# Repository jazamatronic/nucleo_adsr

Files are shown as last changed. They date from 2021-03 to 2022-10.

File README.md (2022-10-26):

# nucleo_adsr
STM32L432 based triple ADSR envelope generator



Very small sound demo with it in action [here](https://imgur.com/a/Ze2JWVJ)

ST generated files have their own license headers.

*NOTE* - R1, R5 and R9 should be 100k, not 2k as shown in the schematics.

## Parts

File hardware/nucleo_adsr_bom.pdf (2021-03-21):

Feuille1

# nucleo_adsr

Sun Mar 21 23:03:33 2021
Eeschema 5.1.5+dfsg1-2build2 Component Count:64
Ref | Value | Description
C1, C2, C3, C4, C5, C6, C13, C15 | 0.1u | Polarized capacitor, small symbol
C7, C8, C9 | 100p | Unpolarized capacitor, small symbol
C10, C11, C12 | 10n | Unpolarized capacitor, small symbol
C14, C16 | 10u | Polarized capacitor, small symbol
D1 | LED_RABG | RGB LED, red/anode/blue/green
J1 | ENV1 | Audio Jack, 2 Poles (Mono / TS), Switched T Pole (Normalling)
J2 | TRIG1 | Audio Jack, 2 Poles (Mono / TS), Switched T Pole (Normalling)
J3 | ENV2 | Audio Jack, 2 Poles (Mono / TS), Switched T Pole (Normalling)
J4 | TRIG2 | Audio Jack, 2 Poles (Mono / TS), Switched T Pole (Normalling)
J5 | ENV3 | Audio Jack, 2 Poles (Mono / TS), Switched T Pole (Normalling)
J6 | TRIG3 | Audio Jack, 2 Poles (Mono / TS), Switched T Pole (Normalling)
J7 | PWR_HDR | Generic connector, double row, 02x08, odd/even pin numbering scheme
Q1, Q2, Q3, Q4, Q5, Q6 | BC547 | 0.1A Ic, 45V Vce, Small Signal NPN Transistor, TO-92
R1, R5, R9 | 2k | Resistor, small symbol
R2, R6, R10 | 1k | Resistor, small symbol
R3, R7, R11 | 10k | Resistor, small symbol
R4, R8, R12 | 4k7 | Resistor, small symbol
R13, R14, R15 | 100k | Resistor, small symbol
R16, R17, R18 | 3k6 | Resistor, small symbol
R19, R20, R21 | 68k | Resistor, small symbol
RV1, RV2, RV3 | 100k | Potentiometer
RVA1, RVD1, RVR1, RVS1 | 100k
SW1 | SW_Push | Push button switch, generic, two pins
U1 | NUCLEO-L432KC
U2, U3, U4 | LF398_SOIC14 | Sample And Hold Unity Gain Follower, SOIC-14
U5 | TL074 | Quad Low-Noise JFET-Input Operational Amplifiers, DIP-14/SOIC-14

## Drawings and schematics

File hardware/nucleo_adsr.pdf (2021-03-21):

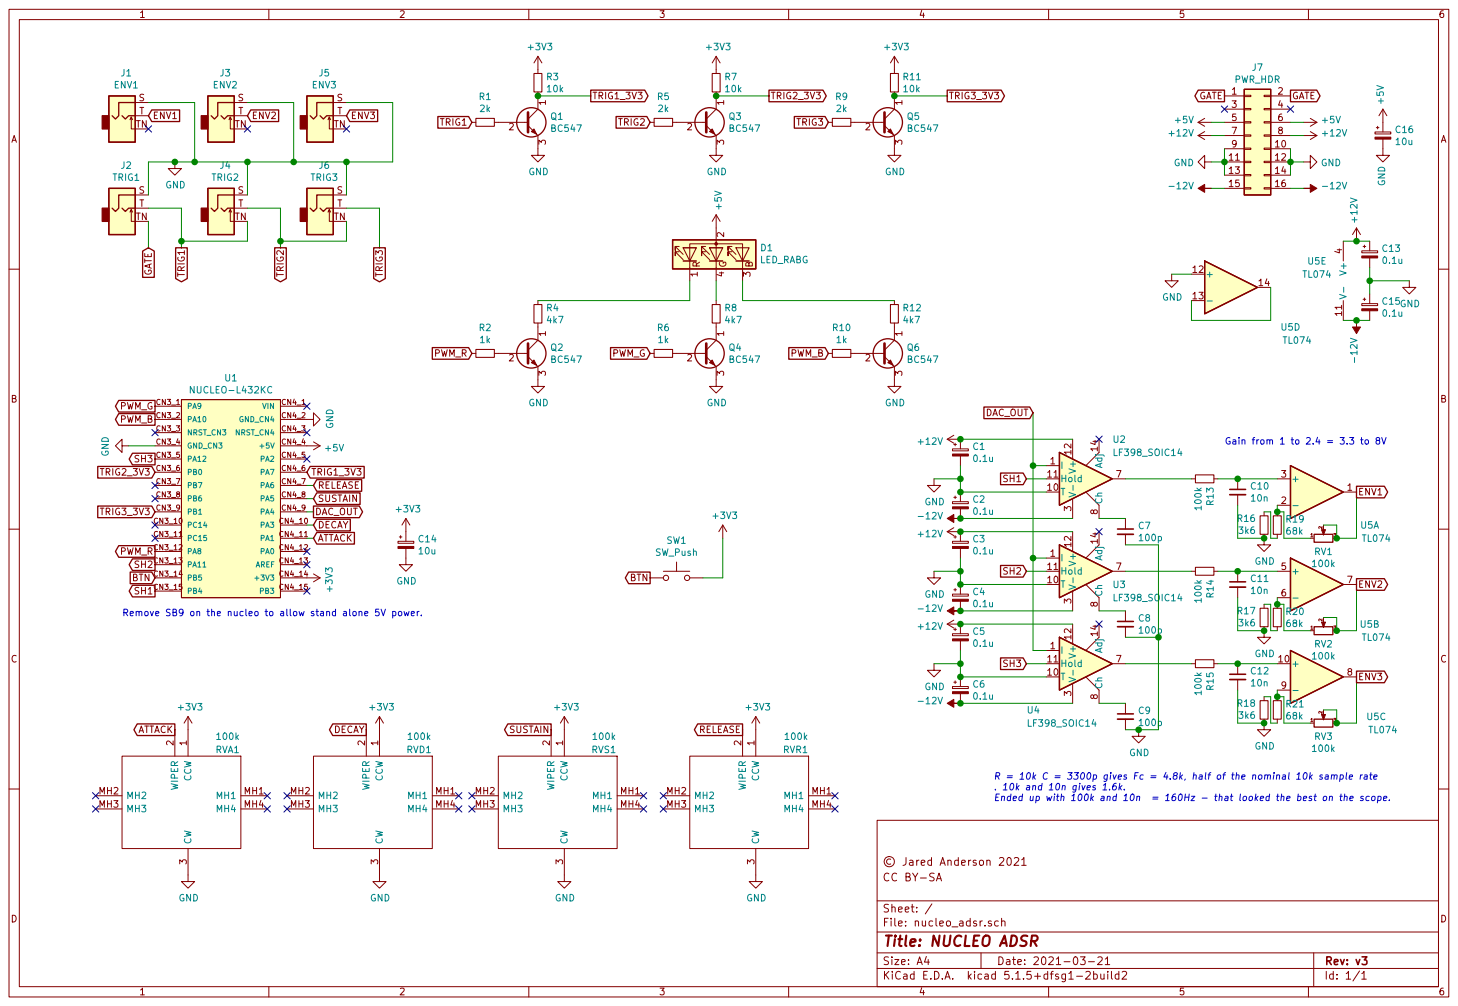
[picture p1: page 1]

11 | 12
13 | 14

Ended up with 100k and 10n = 160Hz - that looked the best on the scope. Gain from 1 to 2.4 = 3.3 to 8V Remove SB9 on the nucleo to allow stand alone 5V power.
100k GND

File: nucleo_adsr.sch Sheet: / CC BY-SA © Jared Anderson 2021

Id: 1/1 Title: NUCLEO ADSR

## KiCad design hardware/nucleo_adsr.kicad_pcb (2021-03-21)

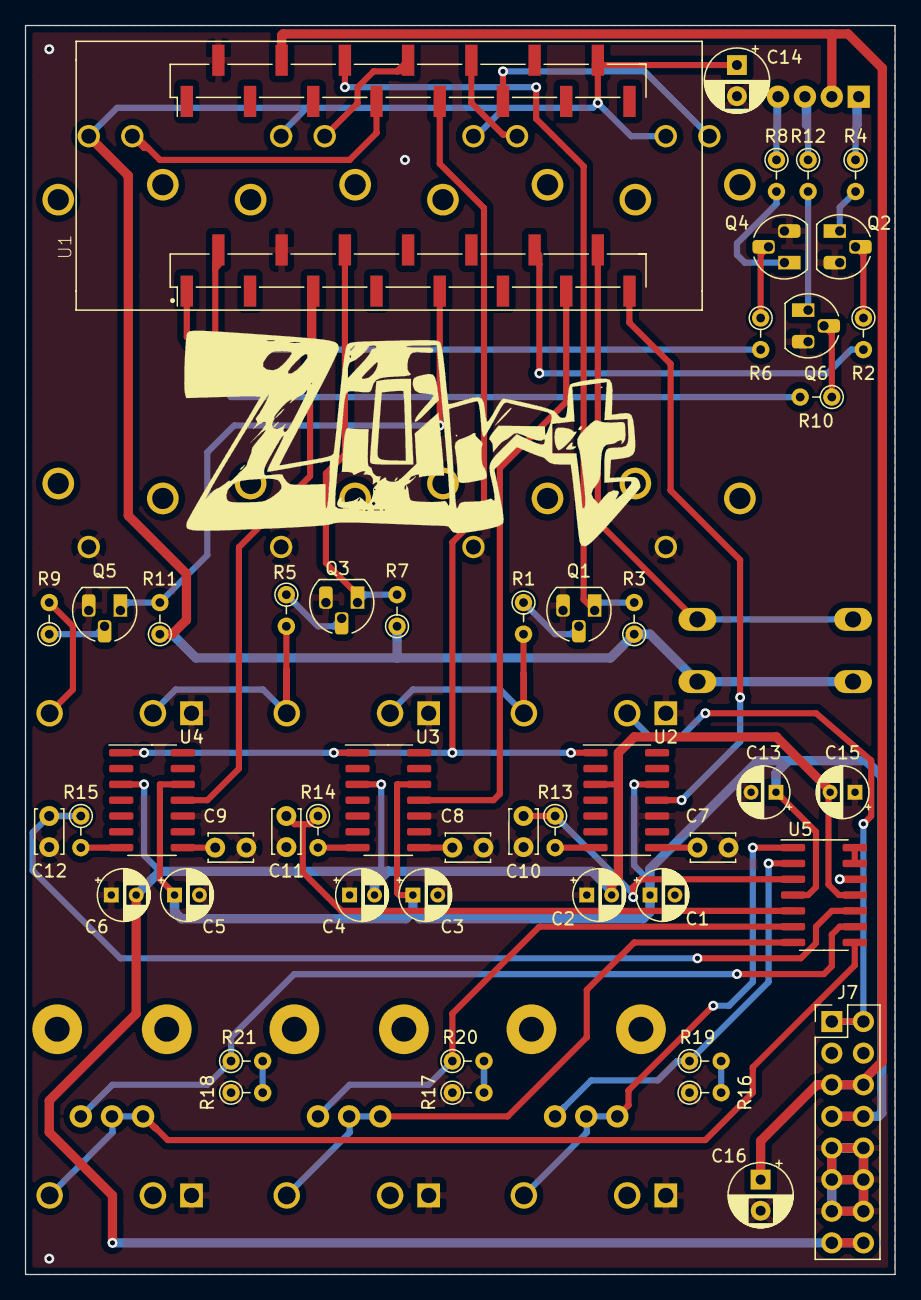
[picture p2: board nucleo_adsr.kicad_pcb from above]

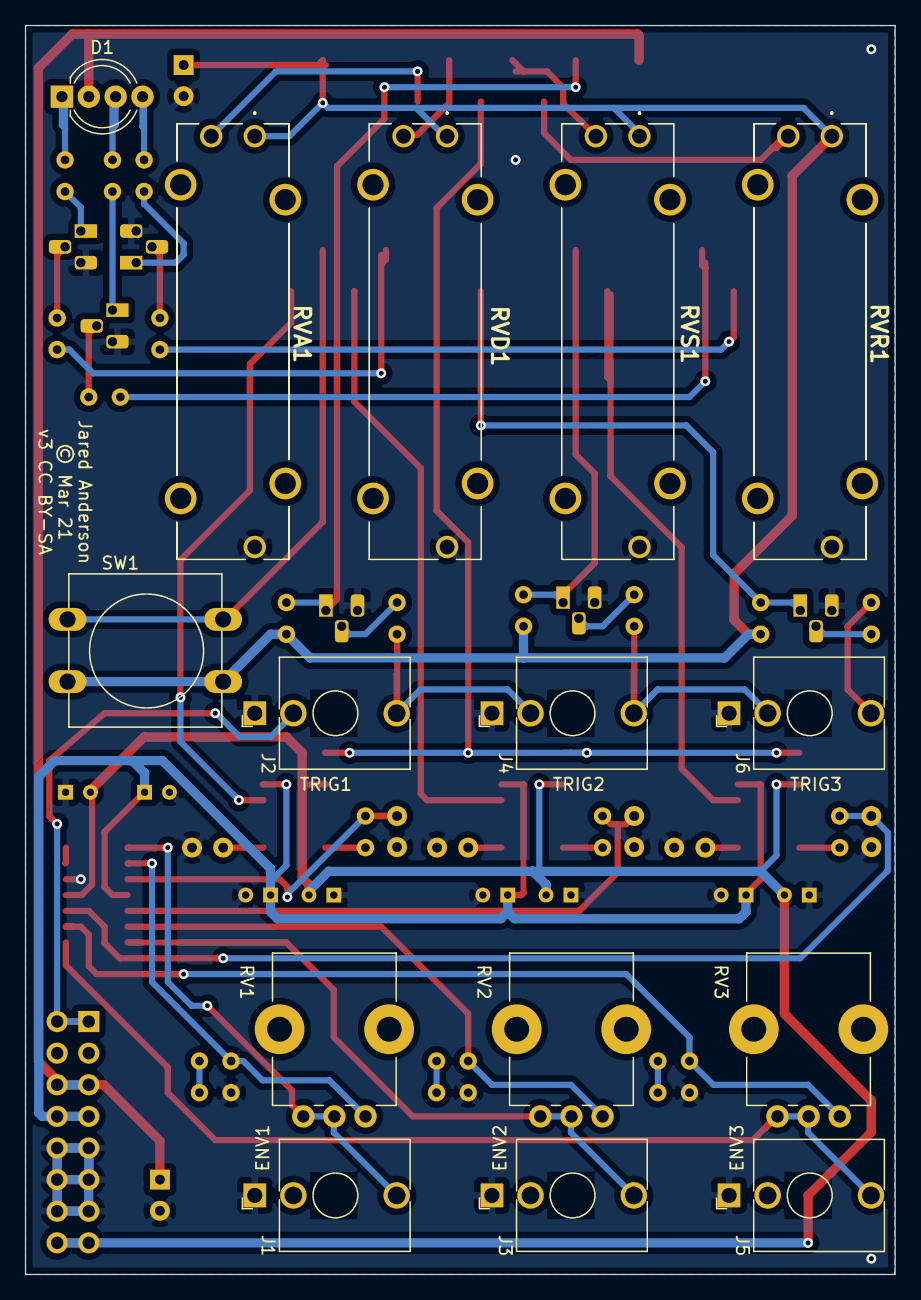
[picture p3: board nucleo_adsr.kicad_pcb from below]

Board: 2 copper layers, 69.8 x 100.3 mm, 64 parts (15 on the bottom side), 55 nets.

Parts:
C1, C2, C3, C4, C5, C6, C13, C15: 0.1u; CP_Radial_D4.0mm_P2.00mm
C7, C8, C9: 100p; C_Disc_D3.4mm_W2.1mm_P2.50mm
C10, C11, C12: 10n; C_Disc_D3.4mm_W2.1mm_P2.50mm
C14, C16: 10u; CP_Radial_D5.0mm_P2.50mm
D1: LED_RABG; LED_D5.0mm-4_RGB_Wide_Pins
J1: ENV1; Jack_3.5mm_QingPu_WQP-PJ398SM_Vertical_CircularHoles
J2: TRIG1; Jack_3.5mm_QingPu_WQP-PJ398SM_Vertical_CircularHoles
J3: ENV2; Jack_3.5mm_QingPu_WQP-PJ398SM_Vertical_CircularHoles
J4: TRIG2; Jack_3.5mm_QingPu_WQP-PJ398SM_Vertical_CircularHoles
J5: ENV3; Jack_3.5mm_QingPu_WQP-PJ398SM_Vertical_CircularHoles
J6: TRIG3; Jack_3.5mm_QingPu_WQP-PJ398SM_Vertical_CircularHoles
J7: PWR_HDR; PinHeader_2x08_P2.54mm_Vertical
Q1, Q2, Q3, Q4, Q5, Q6: BC547; TO-92_HandSolder
R1, R5, R9: 2k; R_Axial_DIN0204_L3.6mm_D1.6mm_P2.54mm_Vertical
R2, R6, R10: 1k; R_Axial_DIN0204_L3.6mm_D1.6mm_P2.54mm_Vertical
R3, R7, R11: 10k; R_Axial_DIN0204_L3.6mm_D1.6mm_P2.54mm_Vertical
R4, R8, R12: 4k7; R_Axial_DIN0204_L3.6mm_D1.6mm_P2.54mm_Vertical
R13, R14, R15: 100k; R_Axial_DIN0204_L3.6mm_D1.6mm_P2.54mm_Vertical
R16, R17, R18: 3k6; R_Axial_DIN0204_L3.6mm_D1.6mm_P2.54mm_Vertical
R19, R20, R21: 68k; R_Axial_DIN0204_L3.6mm_D1.6mm_P2.54mm_Vertical
RV1, RV2, RV3: 100k; Potentiometer_Bourns_PTV09A-1_Single_Vertical
RVA1: 100k; PTA20432010CIB103
RVD1: 100k; PTA20432010CIB103
RVR1: 100k; PTA20432010CIB103
RVS1: 100k; PTA20432010CIB103
SW1: SW_Push; SW_PUSH-12mm
U1: NUCLEO-L432KC; MODULE_NUCLEO-L432KC_SMT
U2, U3, U4: LF398_SOIC14; SOIC-14_3.9x8.7mm_P1.27mm
U5: TL074; SOIC-14_3.9x8.7mm_P1.27mm

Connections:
+3V3: C14.1, R3.1, R7.1, R11.1, RVA1.1, RVD1.1, RVR1.1, RVS1.1, SW1.2, U1.CN4_14
+5V: C16.1, D1.2, J7.5, J7.6, U1.CN4_4
+12V: C1.1, C3.1, C5.1, C13.1, J7.7, J7.8, U2.12, U3.12, U4.12, U5.4
-12V: C2.2, C4.2, C6.2, C15.2, J7.15, J7.16, U2.3, U3.3, U4.3, U5.11
ATTACK: RVA1.2, U1.CN4_11
BTN: SW1.1, U1.CN3_14
DAC_OUT: U1.CN4_9, U2.1, U3.1, U4.1
DECAY: RVD1.2, U1.CN4_10
ENV1: J1.T, RV1.2, RV1.3, U5.1
ENV2: J3.T, RV2.2, RV2.3, U5.7
ENV3: J5.T, RV3.2, RV3.3, U5.8
GATE: J2.TN, J7.1, J7.2
GND: C1.2, C2.1, C3.2, C4.1, C5.2, C6.1, C7.2, C8.2, C9.2, C10.2, C11.2, C12.2, C13.2, C14.2, C15.1, C16.2, J1.S, J2.S, J3.S, J4.S, J5.S, J6.S, J7.9, J7.10, J7.11, J7.12, J7.13, J7.14, Q1.3, Q2.3, Q3.3, Q4.3, Q5.3, Q6.3, R16.1, R17.1, R18.1, RVA1.3, RVD1.3, RVR1.3, RVS1.3, U1.CN3_4, U1.CN4_2, U2.10, U3.10, U4.10, U5.12
unnamed: C7.1, U2.8
unnamed: C8.1, U3.8
unnamed: C9.1, U4.8
unnamed: C10.1, R13.1, U5.3
unnamed: C11.1, R14.1, U5.5
unnamed: C12.1, R15.1, U5.10
unnamed: D1.1, R4.1
unnamed: D1.3, R12.1
unnamed: D1.4, R8.1
unnamed: Q1.2, R1.1
unnamed: Q2.1, R4.2
unnamed: Q2.2, R2.1
unnamed: Q3.2, R5.1
unnamed: Q4.1, R8.2
unnamed: Q4.2, R6.1
unnamed: Q5.2, R9.1
unnamed: Q6.1, R12.2
unnamed: Q6.2, R10.1
unnamed: R13.2, U2.7
unnamed: R14.2, U3.7
unnamed: R15.2, U4.7
unnamed: R16.2, R19.2
unnamed: R17.2, R20.2
unnamed: R18.2, R21.2
unnamed: R19.1, RV1.1, U5.2
unnamed: R20.1, RV2.1, U5.6
unnamed: R21.1, RV3.1, U5.9
unnamed: U5.13, U5.14
PWM_B: R10.2, U1.CN3_2
PWM_G: R6.2, U1.CN3_1
PWM_R: R2.2, U1.CN3_12
RELEASE: RVR1.2, U1.CN4_7
SH1: U1.CN3_15, U2.11
SH2: U1.CN3_13, U3.11
SH3: U1.CN3_5, U4.11
SUSTAIN: RVS1.2, U1.CN4_8
TRIG1: J2.T, J4.TN, R1.2
TRIG1_3V3: Q1.1, R3.2, U1.CN4_6
TRIG2: J4.T, J6.TN, R5.2
TRIG2_3V3: Q3.1, R7.2, U1.CN3_6
TRIG3: J6.T, R9.2
TRIG3_3V3: Q5.1, R11.2, U1.CN3_9

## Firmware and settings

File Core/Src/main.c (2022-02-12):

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
/* Includes ------------------------------------------------------------------*/
#include "main.h"

/* USER CODE BEGIN Includes */
#include <stdlib.h>

#include "envelope.h"
#include "btn.h"
#include "led_rgb.h"

/* USER CODE END Includes */

/* USER CODE BEGIN PD */

/* Definition of ADCx conversions data table size */
#define ADC_CONVERTED_DATA_BUFFER_SIZE   ((uint32_t)  4)   /* Size of array aADCxConvertedData[] */

/* For PWM */
#define  PULSE1_VALUE       (uint32_t)(TIM1_PER/2)
#define  PULSE2_VALUE       (uint32_t)(TIM1_PER/2)
#define  PULSE3_VALUE       (uint32_t)(TIM1_PER/2)

#define TOGGLE_COUNT   1000   

#define BLINK_RATE     750

//#define SH_TIME (uint32_t)7 // give the dac 1us and the LF398 6us

#define GATE_HIGH GPIO_PIN_RESET
#define GATE_LOW  GPIO_PIN_SET

#define SEG_NO_CHANGE 0xFFFF
#define CHANGE_THRESH (ADC_FS / 8)

#define CATCH_THRESH  (ADC_FS / 64)

//#define TOGGLE ; // Debug toggle of LD3 on the nucleo
//#define SEEENVS ; // Debug make the leds flash like an envelope


/* USER CODE END PD */

ADC_HandleTypeDef hadc1;
DMA_HandleTypeDef hdma_adc1;

DAC_HandleTypeDef hdac1;

TIM_HandleTypeDef htim1;
TIM_HandleTypeDef htim6;
TIM_HandleTypeDef htim7;

UART_HandleTypeDef huart2;

/* USER CODE BEGIN PV */
/* Variable containing ADC conversions data */
static uint16_t   aADCxConvertedData[ADC_CONVERTED_DATA_BUFFER_SIZE];

static GPIO_PinState  trigger_pins[3];

//some of these could become flags for efficiency?
#ifdef TOGGLE
static uint16_t	  toggle;
#endif
static uint16_t	  tick, last_tick, btn_tick;
static uint16_t	  dac;
static uint16_t	  sh_timer;
static uint16_t	  i, j;
static uint16_t	  seg_change; // 0xFFFF means no param changed, otherwise 0 -> 3 map to ADSR
static enum curves new_seg;

static env_gen_t envelopes[NUM_ENVS];
static btn_t	 btn;
static led_rgb_t led;

/* USER CODE END PV */

void SystemClock_Config(void);
static void MX_GPIO_Init(void);
static void MX_DMA_Init(void);
static void MX_ADC1_Init(void);
static void MX_USART2_UART_Init(void);
static void MX_DAC1_Init(void);
static void MX_TIM6_Init(void);
static void MX_TIM1_Init(void);
static void MX_TIM7_Init(void);
/* USER CODE BEGIN PFP */

uint16_t catch_param(uint16_t old, uint16_t cur, uint16_t thresh);
/* USER CODE END PFP */

/* USER CODE BEGIN 0 */

uint16_t catch_param(uint16_t old, uint16_t cur, uint16_t thresh)
{
  return (abs(old - cur) < thresh) ? 1 : 0;
}

/* USER CODE END 0 */

/**
  * @brief  The application entry point.
  * @retval int
  */
int main(void)
{
  /* MCU Configuration--------------------------------------------------------*/

  /* Reset of all peripherals, Initializes the Flash interface and the Systick. */
  HAL_Init();

  /* Configure the system clock */
  SystemClock_Config();

  /* Initialize all configured peripherals */
  MX_GPIO_Init();
  MX_DMA_Init();
  MX_ADC1_Init();
  MX_USART2_UART_Init();
  MX_DAC1_Init();
  MX_TIM6_Init();
  MX_TIM1_Init();
  MX_TIM7_Init();
  /* USER CODE BEGIN 2 */

  if (HAL_DAC_Start(&hdac1, DAC_CHANNEL_1) != HAL_OK)
  {
    /* Start Error */
    Error_Handler();
  }

  if (HAL_ADC_Start_DMA(&hadc1,
                        (uint32_t *)aADCxConvertedData,
                        ADC_CONVERTED_DATA_BUFFER_SIZE
                       ) != HAL_OK)
  {
    /* Start Error */
    Error_Handler();
  }

  if (HAL_TIM_Base_Start(&htim6) != HAL_OK)
  {
    /* Start Error */
    Error_Handler();
  }

  /*## Start PWM signals generation #######################################*/
  /* Start channel 1 */
  if (HAL_TIM_PWM_Start(&htim1, TIM_CHANNEL_1) != HAL_OK)
  {
    /* PWM Generation Error */
    Error_Handler();
  }
  /* Start channel 2 */
  if (HAL_TIM_PWM_Start(&htim1, TIM_CHANNEL_2) != HAL_OK)
  {
    /* PWM Generation Error */
    Error_Handler();
  }
  /* Start channel 3 */
  if (HAL_TIM_PWM_Start(&htim1, TIM_CHANNEL_3) != HAL_OK)
  {
    /* PWM generation Error */
    Error_Handler();
  }

#ifdef TOGGLE
  toggle = 0;
#endif
  tick = 0;
  last_tick = 0;
  btn_tick = 1;
  dac = 0;
  sh_timer = 0;
  seg_change = SEG_NO_CHANGE;

  init_btn(&btn);
  init_led_rgb(&led, &htim1, TIM_CHANNEL_1, TIM_CHANNEL_2, TIM_CHANNEL_3);


  for (i = 0; i < NUM_ENVS; i++) {
    init_env(&envelopes[i]);
  }

  i = 0;

  /* USER CODE END 2 */

  /* Infinite loop */
  /* USER CODE BEGIN WHILE */
  while (1)
  {
    /* USER CODE END WHILE */

    /* USER CODE BEGIN 3 */

    if (tick != last_tick) {

#ifdef TOGGLE
      // take care of flashing the LD3 to show signs of life
      toggle++;
      if (toggle >= TOGGLE_COUNT) {
	HAL_GPIO_TogglePin(LD3_GPIO_Port, LD3_Pin);
	toggle = 0;
      }
#endif

      // Check the TRIG inputs
      trigger_pins[0] = HAL_GPIO_ReadPin(GPIOA, TRIG1_Pin);
      trigger_pins[1] = HAL_GPIO_ReadPin(GPIOB, TRIG2_Pin);
      trigger_pins[2] = HAL_GPIO_ReadPin(GPIOB, TRIG3_Pin);

      // Check the envelope pots
      // If we're doing a long press we shouldn't
      if (btn.click_state == LONG) {
	//don't do anything here - we're going to check if they're different below and 
	//update segment shapes choices based on these numbers
	//Basically hold the button and move the pot of the parameter that you want to change shape
      } else {
	for (j = 0; j < 4; j++) {
	  if (seg_unlocked[j] || (seg_unlocked[j] = catch_param(envelopes[i].adsr[j], aADCxConvertedData[j], CATCH_THRESH))) {
	    envelopes[i].adsr[j] = aADCxConvertedData[j];
	  } 
	}
      }

      // Process the envelopes
      process_env(&envelopes[0], (trigger_pins[0] == GATE_HIGH) ? 1 : 0, envelopes[2].end);
      process_env(&envelopes[1], (trigger_pins[1] == GATE_HIGH) ? 1 : 0, envelopes[0].end);
      process_env(&envelopes[2], (trigger_pins[2] == GATE_HIGH) ? 1 : 0, envelopes[1].end);

      // Step through the envs and set the DAC accordingly, give it 1uS to stablelize plus 6uS of Sample time
      if (HAL_DAC_SetValue(&hdac1, DAC_CHANNEL_1, DAC_ALIGN_12B_R, ENV_INV(&envelopes[0])) != HAL_OK)
      {
        /* Setting value Error */
        Error_Handler();
      }
      // Assume 6uS sampling time once DAC is stable
      HAL_GPIO_WritePin(SH1_GPIO_Port, SH1_Pin, GPIO_PIN_SET);
      __HAL_TIM_SET_AUTORELOAD(&htim7, SH_TIME);
      HAL_TIM_Base_Start_IT(&htim7);
      while (!sh_timer) {
	//spin on the timer
      }
      sh_timer = 0;
      HAL_GPIO_WritePin(SH1_GPIO_Port, SH1_Pin, GPIO_PIN_RESET);

      if (HAL_DAC_SetValue(&hdac1, DAC_CHANNEL_1, DAC_ALIGN_12B_R, ENV_INV(&envelopes[1])) != HAL_OK)
      {
        /* Setting value Error */
        Error_Handler();
      }
      HAL_GPIO_WritePin(SH2_GPIO_Port, SH2_Pin, GPIO_PIN_SET);
      __HAL_TIM_SET_AUTORELOAD(&htim7, SH_TIME);
      HAL_TIM_Base_Start_IT(&htim7);
      while (!sh_timer) {
	//spin on the timer
      }
      sh_timer = 0;
      HAL_GPIO_WritePin(SH2_GPIO_Port, SH2_Pin, GPIO_PIN_RESET);

      if (HAL_DAC_SetValue(&hdac1, DAC_CHANNEL_1, DAC_ALIGN_12B_R, ENV_INV(&envelopes[2])) != HAL_OK)
      {
        /* Setting value Error */
        Error_Handler();
      }
      HAL_GPIO_WritePin(SH3_GPIO_Port, SH3_Pin, GPIO_PIN_SET);
      __HAL_TIM_SET_AUTORELOAD(&htim7, SH_TIME);
      HAL_TIM_Base_Start_IT(&htim7);
      while (!sh_timer) {
	//spin on the timer
      }
      sh_timer = 0;
      HAL_GPIO_WritePin(SH3_GPIO_Port, SH3_Pin, GPIO_PIN_RESET);


      // Let's do the button and led every ten ticks which should give us ms resolution
      if ((btn_tick % BTN_TICK) == 0) {

	process_btn(&btn, (HAL_GPIO_ReadPin(BTN_GPIO_Port, BTN_Pin) == GPIO_PIN_SET) ? 1 : 0);

      	switch (btn.click_state) {
      	  case NONE:
	    seg_change = SEG_NO_CHANGE;
      	    break;
      	  case SINGLE:
	    //cycle through the envelopes
      	    i = (i + 1) % NUM_ENVS;
	    for (j = 0; j < 4; j++) {
	      seg_unlocked[j] = 0;
	    }
      	    break;
      	  case DOUBLE:
	    //double click toggles invert of current envelope
      	    envelopes[i].mode = (envelopes[i].mode + 1) % NUM_MODES;
      	    break;
	  case LONG:
	    //This is where I want to check the ADC channels and pick segment shapes based on each third of the range  
	    //Might need to do something to stop doing continuous sampling or continuous update of the envelopes directly
	    //For now only allow adjustment of one segment per long press
	    if (seg_change == SEG_NO_CHANGE) {
	      for (j = 0; j < 4; j++) {
	        if (abs(envelopes[i].adsr[j] - aADCxConvertedData[j]) > CHANGE_THRESH) {
	          seg_change = j;
	        }
	      }
	      led.blink = 0xFF;
	      led.blink_duty = 0x00;
	    } else {

	      if (aADCxConvertedData[seg_change] < BTM_THRD) {
		new_seg = LIN;
	      } else if (aADCxConvertedData[seg_change] < MID_THRD) {
		new_seg = EXP;
	      } else {
		new_seg = LOG;
	      }

	      switch (seg_change) {
		case ATTACK:
		  envelopes[i].acurve = new_seg;
		  break;
		case DECAY:
		  envelopes[i].dcurve = new_seg;
		  break;
		case SUSTAIN:
		  //easter eggs
		  if (new_seg == LOG) {
		    envelopes[i].mode = BOUNCY;
		  } else {
		    envelopes[i].mode = ONESHOT;
		  }
		  break;
		case RELEASE:
		  envelopes[i].rcurve = new_seg;
		  break;
		default:
		  break;
	      }
	      led.blink = 0xFF;
	      led.blink_duty = 0xFF;
	    }
	    break;

      	  default:
      	    break;
      	}

	switch ((btn.click_state == LONG) ? new_seg : i) {
      	  case 0:
      	    led.r = ADC_FS;
      	    led.g = 0;
      	    led.b = TRIG_MODE(&envelopes[i]) ? ADC_FS : 0;
      	    break;
      	  case 1:
      	    led.r = TRIG_MODE(&envelopes[i]) ? ADC_FS : 0;
      	    led.g = ADC_FS;
      	    led.b = 0;
      	    break;
      	  case 2:
      	    led.r = 0;
      	    led.g = TRIG_MODE(&envelopes[i]) ? ADC_FS : 0;
      	    led.b = ADC_FS;
      	    break;
      	  default:
      	    led.r = ADC_FS;
      	    led.g = ADC_FS;
      	    led.b = ADC_FS;
      	}

	if (btn.click_state != LONG) {
	  switch (envelopes[i].mode) {
	    case ONESHOT:
	      led.blink = 0xFF;
	      led.blink_duty = 0xFF;
	      break;
	    case INV_ONESHOT:
	      led.blink = BLINK_RATE;
      	      led.blink_duty = 0.5 * led.blink;
	      break;
	    case TRIG:
	      led.blink = 0xFF;
	      led.blink_duty = 0xFF;
	      break;
	    case INV_TRIG:
	      led.blink = BLINK_RATE;
      	      led.blink_duty = 0.5 * led.blink;
	      break;
	    case LOOP:
	      led.blink = BLINK_RATE;
      	      led.blink_duty = 0.75 * led.blink;
	      break;
	    case INV_LOOP:
	      led.blink = BLINK_RATE;
      	      led.blink_duty = 0.25 * led.blink;
	      break;
	    case BOUNCY:
	      led.blink = 0xFF;
	      led.blink_duty = 0xFF;
	      led.r = envelopes[i].val;
      	      led.g = envelopes[i].val;
      	      led.b = envelopes[i].val;
	      break;
      	  }
	}

#ifdef SEEENVS	
	/*
      	 * Testing - visualize the envs
      	 */
	if (GATE(&envelopes[0], (trigger_pins[0] == GATE_HIGH) ? 1 : 0) || \
	    GATE(&envelopes[1], (trigger_pins[1] == GATE_HIGH) ? 1 : 0) || \
	    GATE(&envelopes[2], (trigger_pins[2] == GATE_HIGH) ? 1 : 0)) { 
	  led.r = ENV_INV(&envelopes[0]);
      	  led.g = ENV_INV(&envelopes[1]);
      	  led.b = ENV_INV(&envelopes[2]);
	}
#endif
      	
      	process_led(&led);

	btn_tick = 1;
      } else {
	btn_tick++;
      }

      tick++;
      last_tick = tick;
    }
  }
  /* USER CODE END 3 */
}

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
/* USER CODE BEGIN 4 */
void HAL_ADC_ConvCpltCallback(ADC_HandleTypeDef* hadc)
{
  if (__HAL_ADC_GET_FLAG(hadc, ADC_FLAG_EOS)) {
    tick = 1;
  }
}

/**
  * @brief  Period elapsed callback in non blocking mode
  * @param  htim : TIM handle
  * @retval None
  */
void HAL_TIM_PeriodElapsedCallback(TIM_HandleTypeDef *htim)
{
  if (htim->Instance == TIM7) {
    HAL_TIM_Base_Stop_IT(htim);
    sh_timer++;
  }
}

/* USER CODE END 4 */
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


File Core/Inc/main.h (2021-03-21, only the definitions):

#define TIM6_PSC 363
#define TIM6_PER 22
#define TIM1_PSC 4
#define TIM1_PER 8191
#define TIM7_PSC 79
#define SH_TIME 7
#define MCO_Pin GPIO_PIN_0
#define MCO_GPIO_Port GPIOA
#define ADC_A_Pin GPIO_PIN_1
#define ADC_A_GPIO_Port GPIOA
#define VCP_TX_Pin GPIO_PIN_2
#define VCP_TX_GPIO_Port GPIOA
#define ADC_D_Pin GPIO_PIN_3
#define ADC_D_GPIO_Port GPIOA
#define ADC_S_Pin GPIO_PIN_5
#define ADC_S_GPIO_Port GPIOA
#define ADC_R_Pin GPIO_PIN_6
#define ADC_R_GPIO_Port GPIOA
#define TRIG1_Pin GPIO_PIN_7
#define TRIG1_GPIO_Port GPIOA
#define TRIG2_Pin GPIO_PIN_0
#define TRIG2_GPIO_Port GPIOB
#define TRIG3_Pin GPIO_PIN_1
#define TRIG3_GPIO_Port GPIOB
#define PWM_R_Pin GPIO_PIN_8
#define PWM_R_GPIO_Port GPIOA
#define PWM_G_Pin GPIO_PIN_9
#define PWM_G_GPIO_Port GPIOA
#define PWM_B_Pin GPIO_PIN_10
#define PWM_B_GPIO_Port GPIOA
#define SH2_Pin GPIO_PIN_11
#define SH2_GPIO_Port GPIOA
#define SH3_Pin GPIO_PIN_12
#define SH3_GPIO_Port GPIOA
#define SWDIO_Pin GPIO_PIN_13
#define SWDIO_GPIO_Port GPIOA
#define SWCLK_Pin GPIO_PIN_14
#define SWCLK_GPIO_Port GPIOA
#define VCP_RX_Pin GPIO_PIN_15
#define VCP_RX_GPIO_Port GPIOA
#define LD3_Pin GPIO_PIN_3
#define LD3_GPIO_Port GPIOB
#define SH1_Pin GPIO_PIN_4
#define SH1_GPIO_Port GPIOB
#define BTN_Pin GPIO_PIN_5
#define BTN_GPIO_Port GPIOB

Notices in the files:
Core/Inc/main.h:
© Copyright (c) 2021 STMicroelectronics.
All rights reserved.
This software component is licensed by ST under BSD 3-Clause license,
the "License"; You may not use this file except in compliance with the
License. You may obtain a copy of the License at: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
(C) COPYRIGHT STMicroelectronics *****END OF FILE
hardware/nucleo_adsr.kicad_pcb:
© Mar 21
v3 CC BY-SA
